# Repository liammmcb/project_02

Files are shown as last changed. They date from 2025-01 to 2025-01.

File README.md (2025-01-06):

# Replica Lightsaber PCB

This repository contains all needed files to create a PCB for the lightsaber as outlined in the lightsaber directory. The purpose of the PCB is to recreate all hardware connectivity currently being used by the PocketBeagle.

The EAGLE folder contains all files related to the EAGLE app, a PCB designer. It contains the library file (.lbr), the schematic file (.sch) and the board layout file (.brd) for the lightsaber PCB. The MFG-folder contains all files for PCB manufacturing, including assembly files, drill files, and gerber files.

The docs folder contains a PowerPoint outlining the background of the project, along with various block diagrams. Additionally, the top and bottom layers of the PCB, along with the schematic are included in this folder.

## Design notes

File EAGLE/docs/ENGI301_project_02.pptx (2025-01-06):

## EDES 301 PCB Project

Liam McConnico-Blanchet
Due 12/17/2024 @ 11:59pm

## Background Information

- I’ve wanted to have my own replica lightsaber for a long time, but they’re too expensive
  - Being able to make our own lightsaber means it will be both cheaper and more personal
  - Since I don’t want an exact lightsaber replica, I will be able to add a lot more features than a regular replica lightsaber.
  - Similar projects
    - NeoPixel Lightsaber: https://www.hackster.io/Modustrial_Maker/neopixel-lightsabers-w-party-modes-arduino-controlled-3e5a0d
    - ENGI 301 Elemental Cosplay Sword: https://www.hackster.io/Eunice011/elemental-cosplay-sword-1821f4
    - Wizard’s Walking Staff: https://www.hackster.io/Lucas_Ainsworth/wizard-s-walking-staff-ed7e08
- Incorporate aspects of different designs (movement of the wizard staff, lightsaber-ness of the NeoPixel Lightsaber, light ups of ENGI 301 cosplay sword) to get a fuller lightsaber experience.

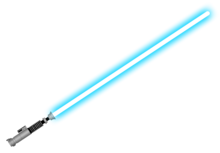
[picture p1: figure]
Lightsaber - Wikipedia

X =

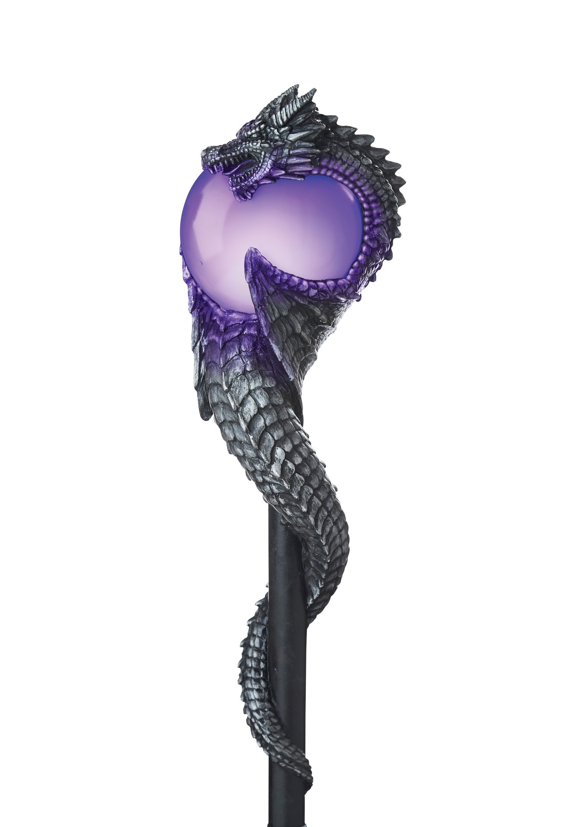
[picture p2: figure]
Amazon.com: California Costumes Wizard Staff : Clothing, Shoes & Jewelry

ENGI 301
Lightsaber
Staff

## System Block Diagram

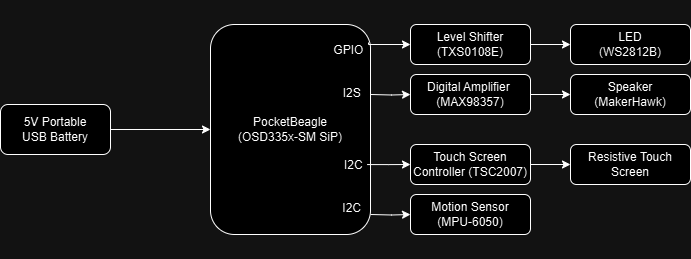
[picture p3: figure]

## Software Block Diagram

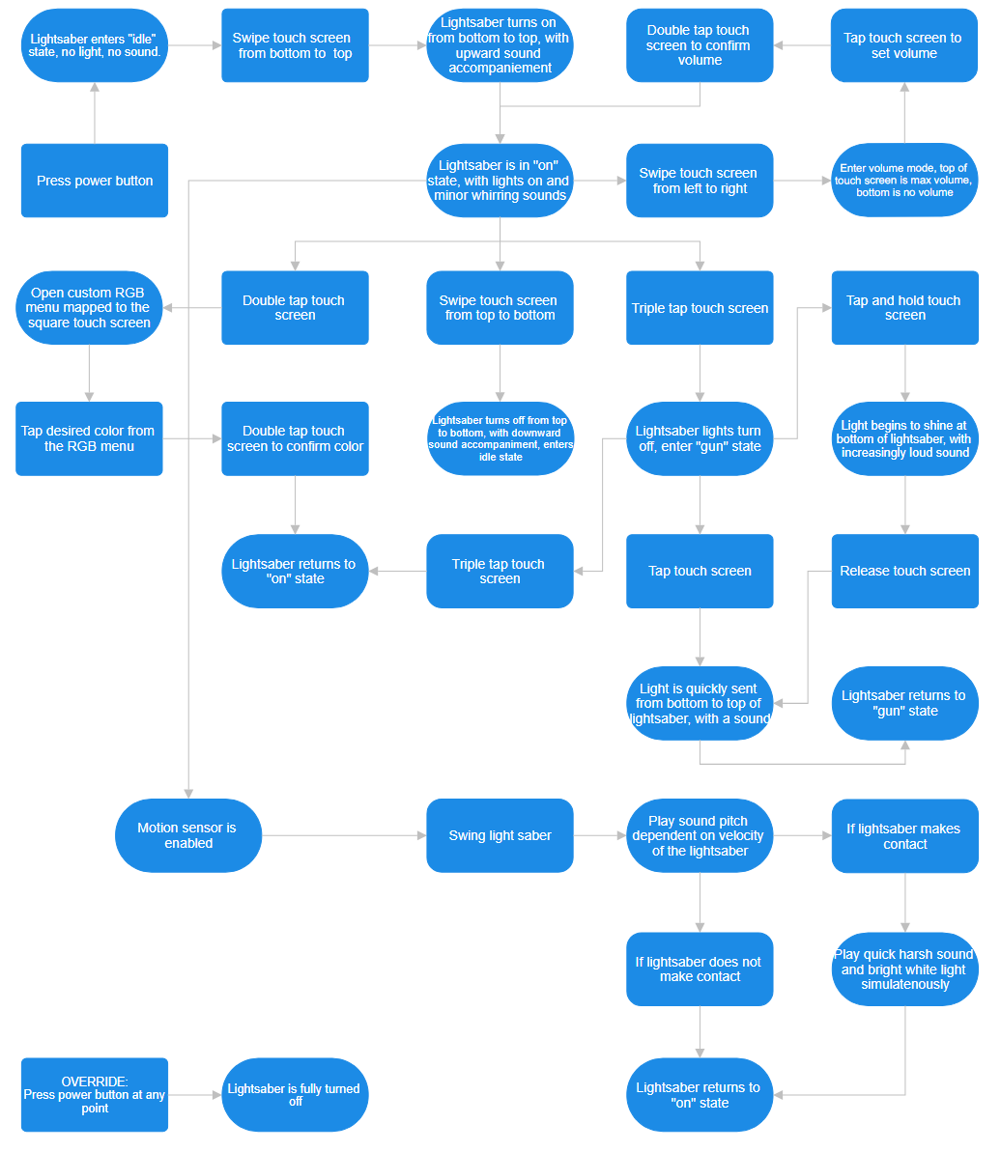
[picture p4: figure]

## Mechanical Block Diagram

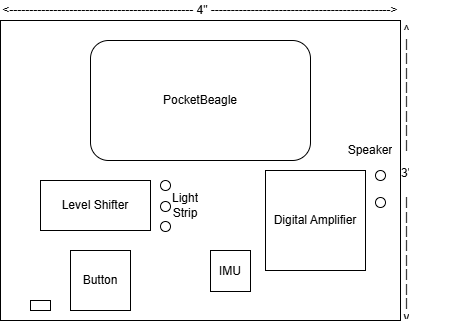
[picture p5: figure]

Complete For Project 2
See next slide for an example

FRONT

BACK

FRONT

## Bill of Materials

Component | Cost
LED Reel (16.4ft) (https://www.amazon.com/BTF-LIGHTING-Flexible-Individually-Addressable-Non-waterproof/dp/B01CDTEJBG) | $27.99
IMU 5pc (https://www.amazon.com/MPU-6050-MPU6050-Accelerometer-Gyroscope-Converter/dp/B07RXQGGJX?th=1) | $12.99
Speakers 2pc (https://www.amazon.com/MakerHawk-Full-Range-Advertising-Connector-Separating/dp/B07GJ4GH67) | $11.99
Digital Amplifier (https://www.adafruit.com/product/3006?gad_source=1) | $5.95
5V Portable USB Battery 2pc (https://www.amazon.com/SIXTHGU-Portable-Charger-Charging-Flashlight/dp/B0C7PHKKNK) | $17.99
Resistive Touch Screen (https://www.adafruit.com/product/333) | $5.95
Resistive Touch Screen Controller (https://www.adafruit.com/product/5423) | $4.95
Total | $87.81

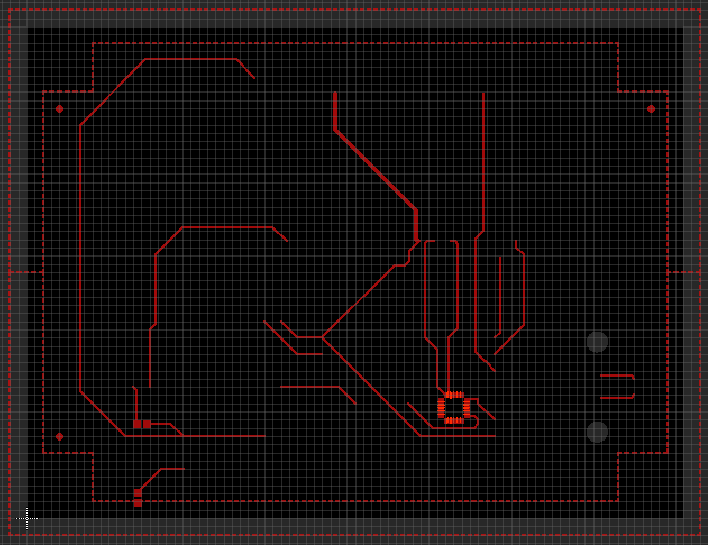
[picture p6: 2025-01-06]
EAGLE/docs/top_layer.png

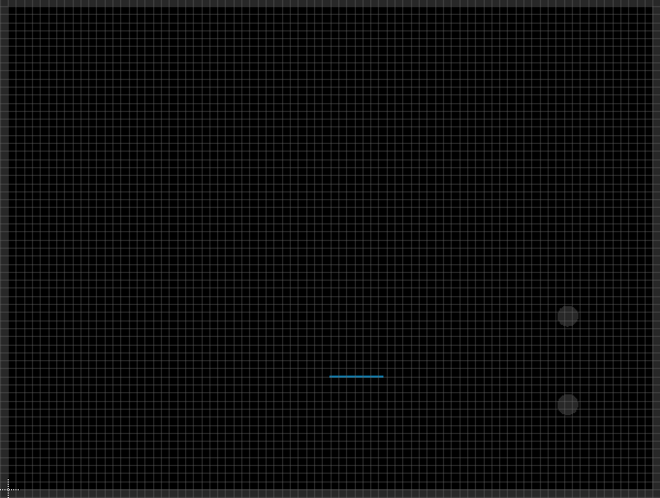
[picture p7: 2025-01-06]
EAGLE/docs/bot_layer.png

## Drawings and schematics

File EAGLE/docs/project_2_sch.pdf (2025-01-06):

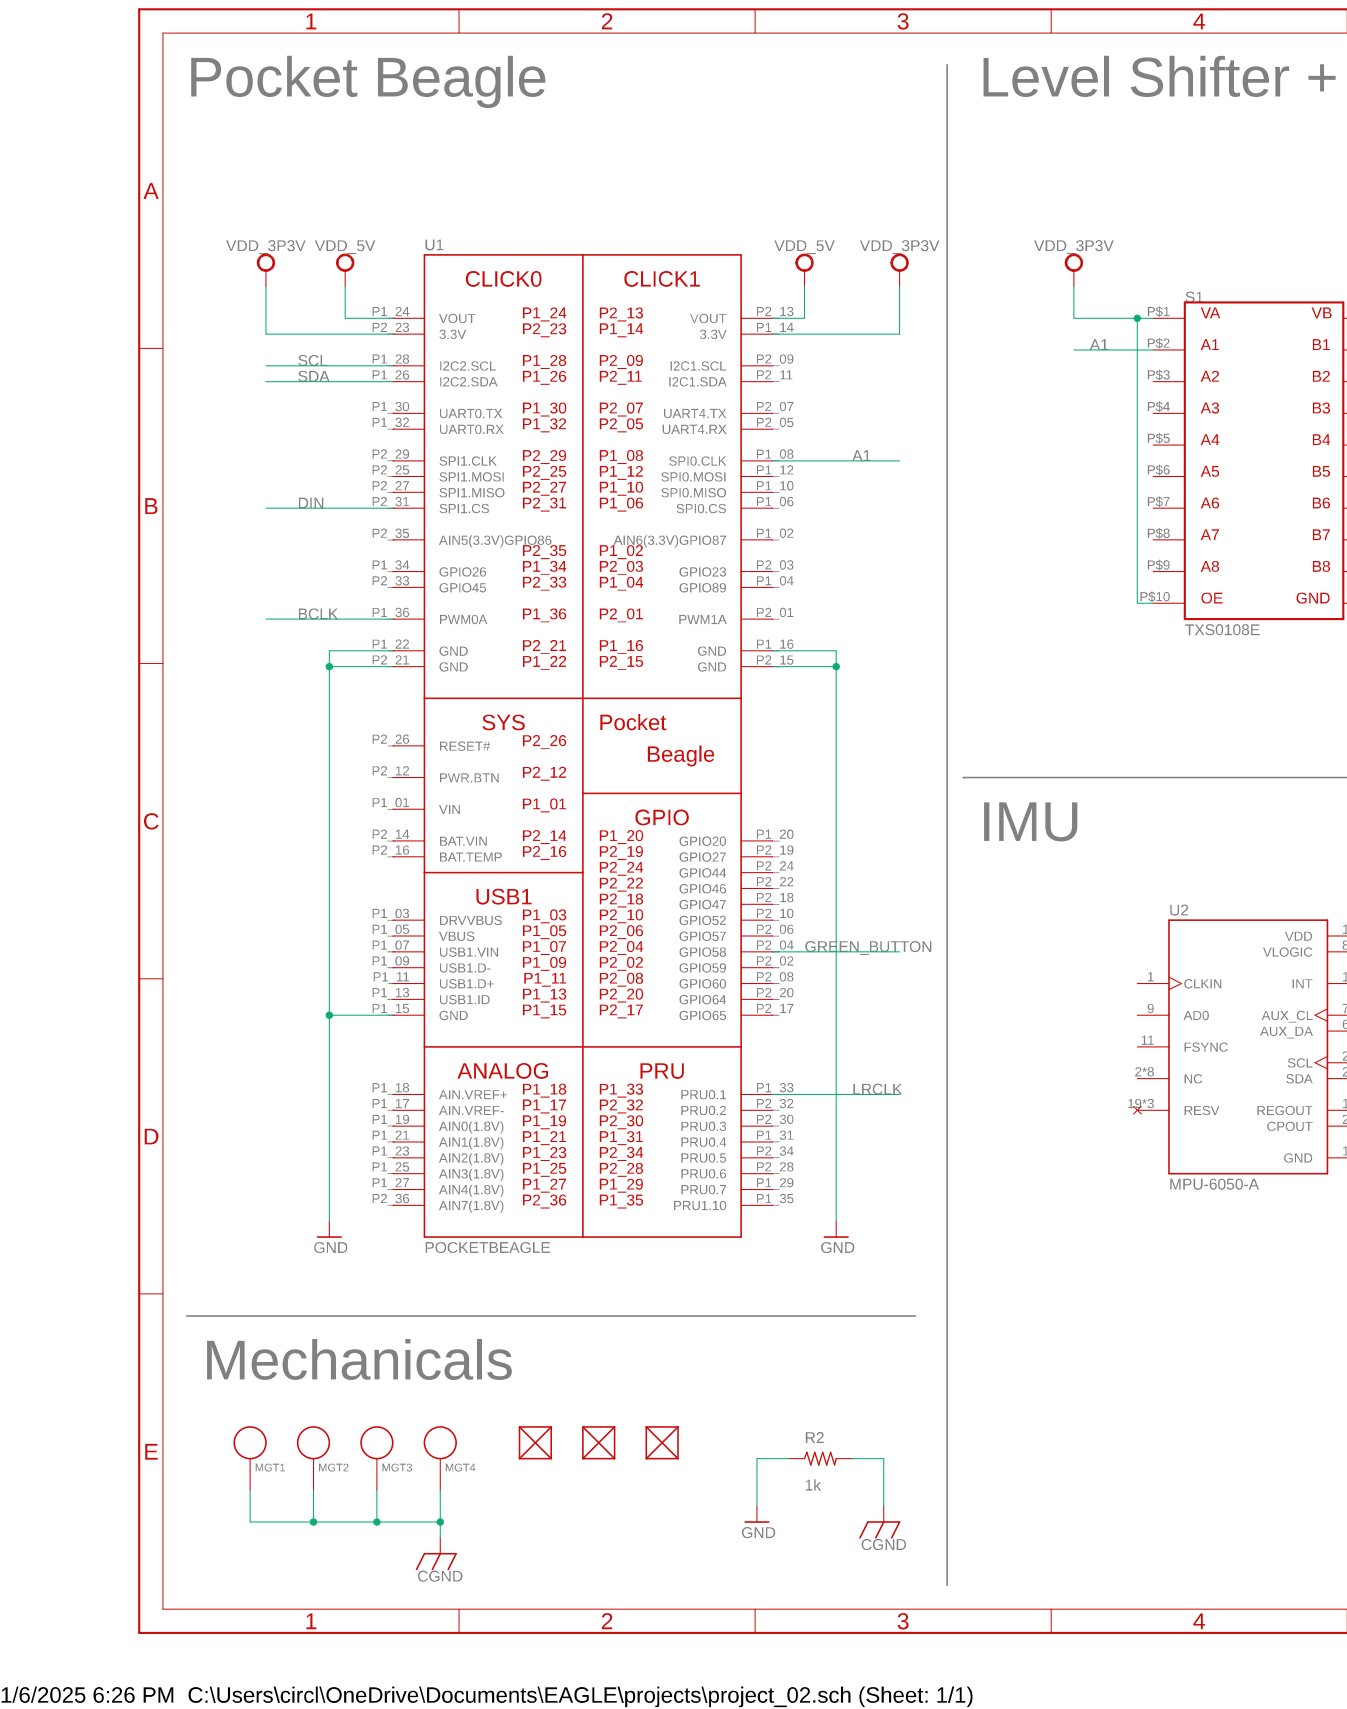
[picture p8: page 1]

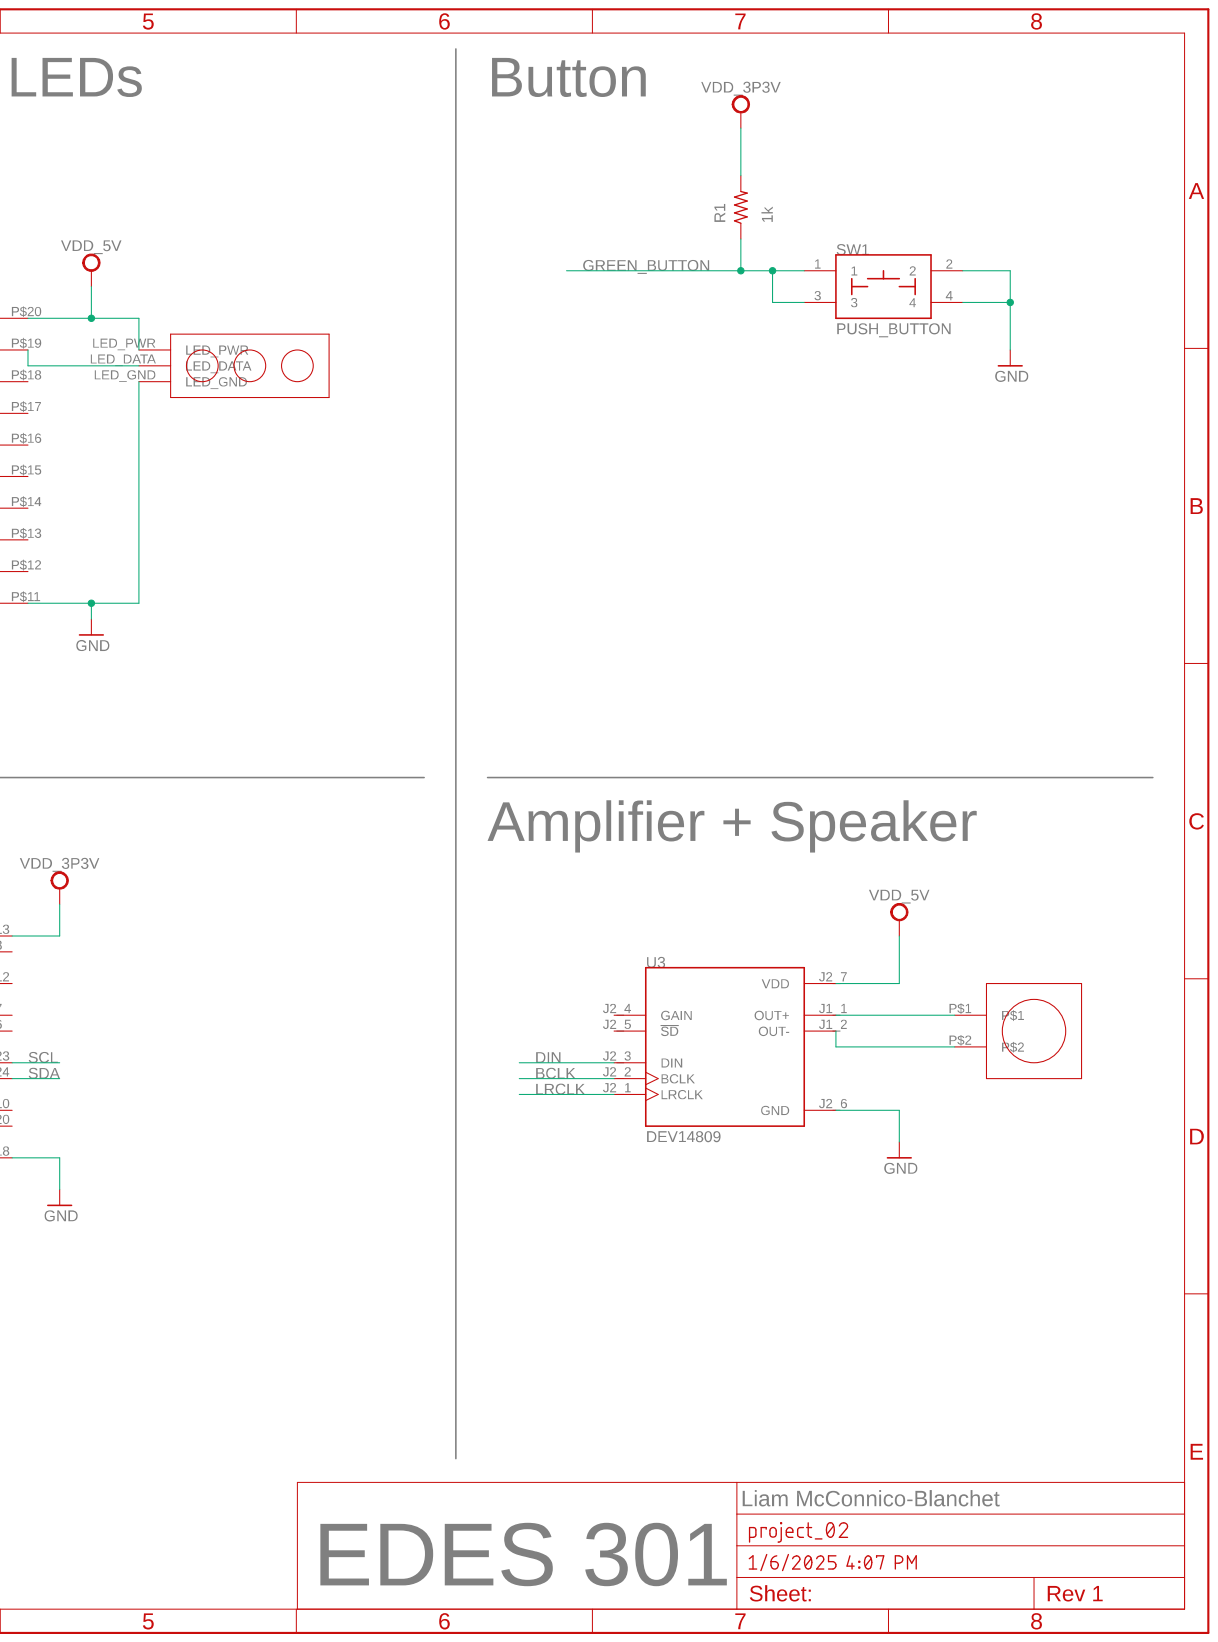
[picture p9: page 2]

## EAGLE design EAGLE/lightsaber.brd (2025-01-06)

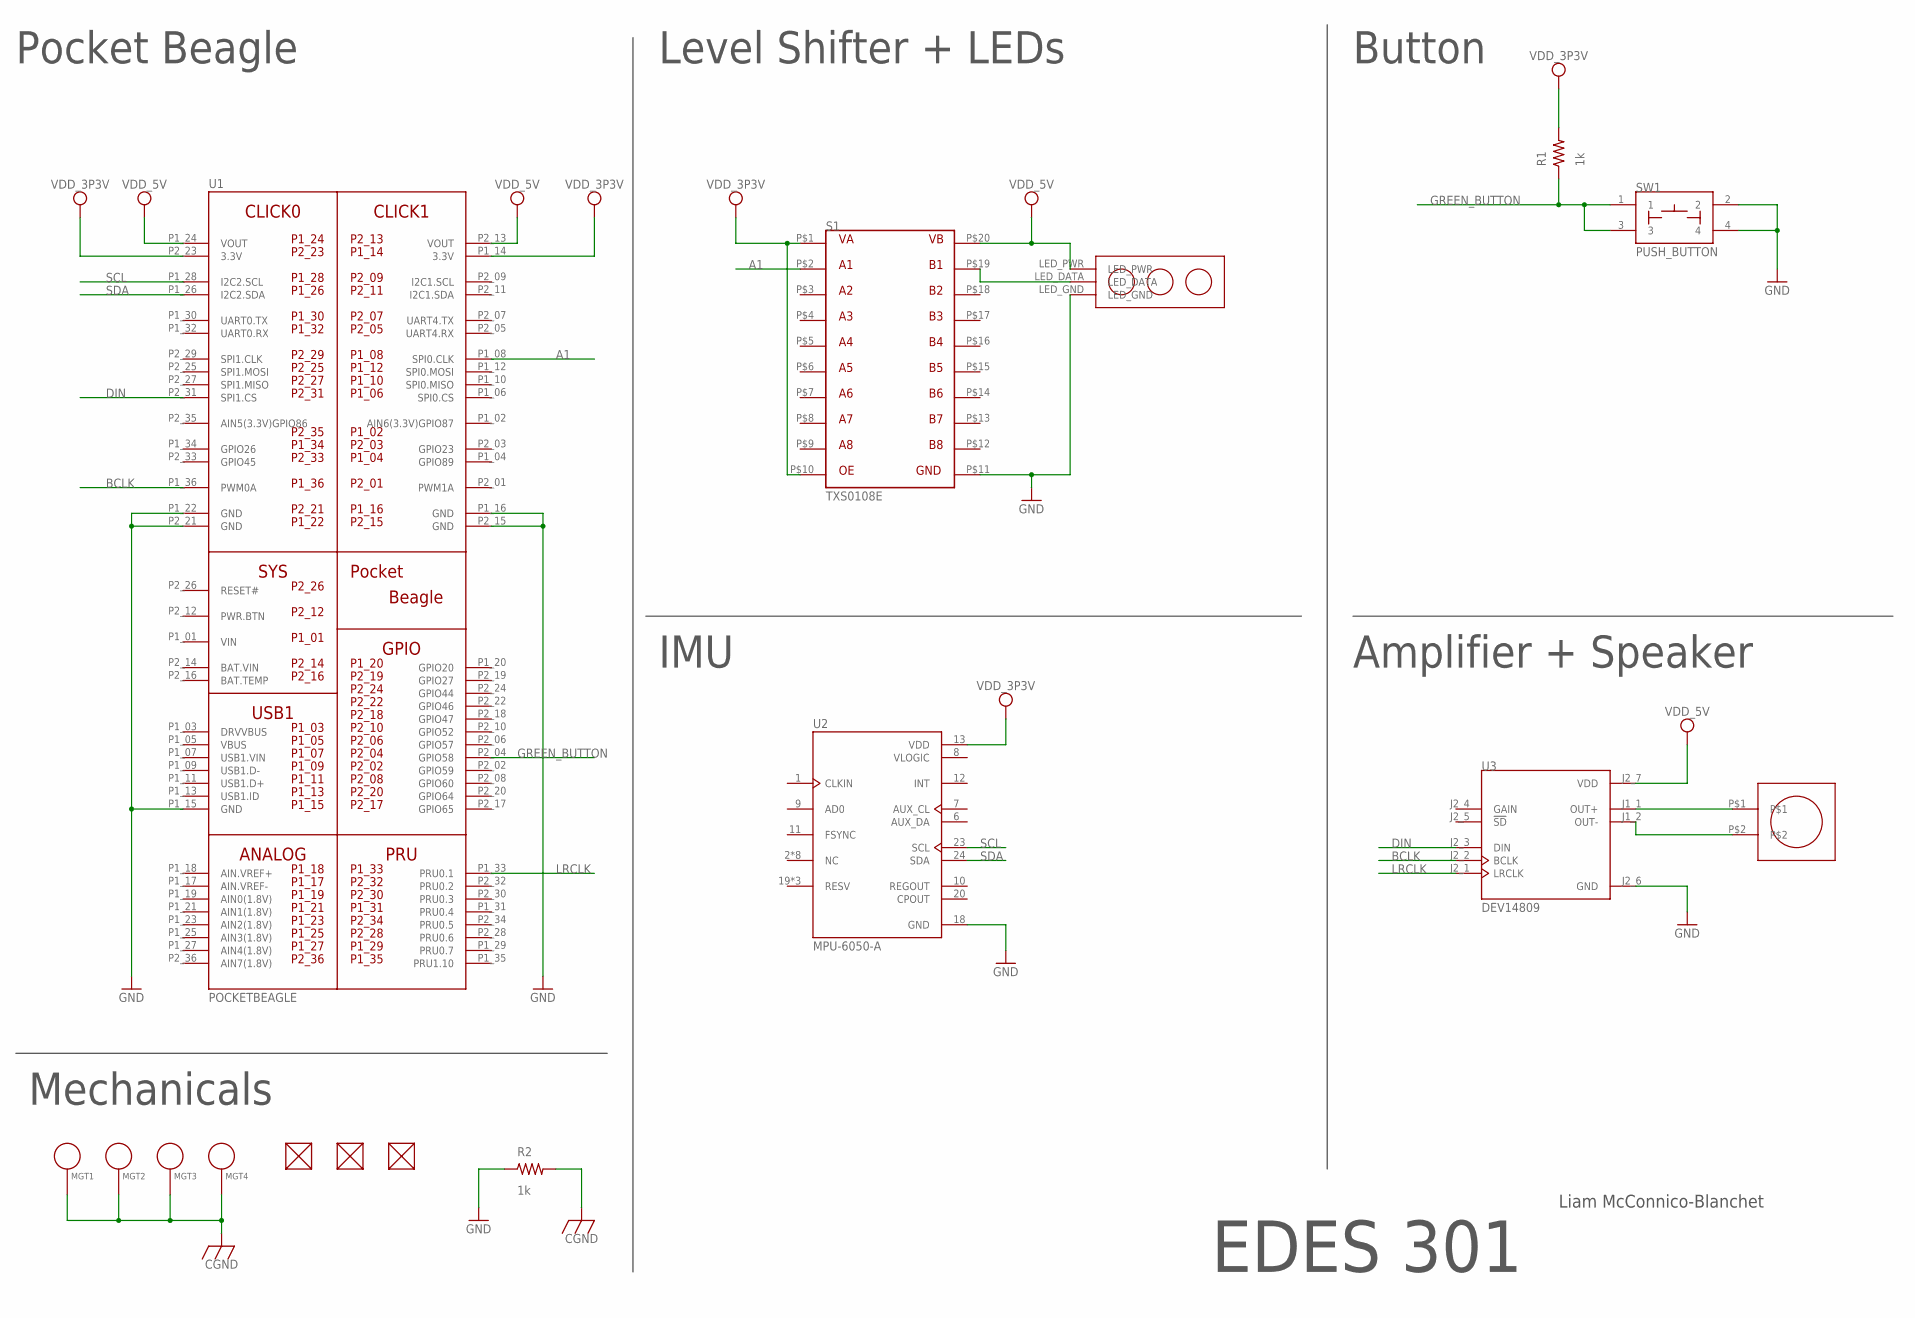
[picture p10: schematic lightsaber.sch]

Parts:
FUD1, FUD2, FUD3: FIDUCIAL; FIDUCIAL_40MIL
MGT1, MGT2, MGT3, MGT4: MOUNTING_HOLE
R1, R2: 1k; R0603
S1: TXS0108E
SW1: PUSH_BUTTON; BUTTON_12.5MM
U1: POCKETBEAGLE
U2: MPU-6050-A; QFN50P400X400X95-24N
U3: DEV14809; MODULE_DEV14809
U$1: LED_STRIP
U$2: SPEAKER

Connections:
A1: S1.P$2, U1.P1_08 (SPI0.CLK)
BAT.VIN: U1.P2_14 (BAT.VIN)
BCLK: U1.P1_36 (PWM0A), U3.J2_2 (BCLK)
CGND: MGT1.P$1, MGT2.P$1, MGT3.P$1, MGT4.P$1, R2.2
DIN: U1.P2_31 (SPI1.CS), U3.J2_3 (DIN)
GND: R2.1, S1.P$11, SW1.2, SW1.4, U1.P1_15 (GND), U1.P1_16 (GND), U1.P1_22 (GND), U1.P2_15 (GND), U1.P2_21 (GND), U2.18 (GND), U3.J2_6 (GND), U$1.LED_GND
GREEN_BUTTON: R1.1, SW1.1, SW1.3, U1.P2_04 (GPIO58)
LRCLK: U1.P1_33 (PRU0.1), U3.J2_1 (LRCLK)
unnamed: U3.J1_1 (OUT+), U$2.P$1
unnamed: U3.J1_2 (OUT-), U$2.P$2
unnamed: S1.P$19, U$1.LED_DATA
SCL: U1.P1_28 (I2C2.SCL), U2.23 (SCL)
SDA: U1.P1_26 (I2C2.SDA), U2.24 (SDA)
VDD_3P3V: R1.2, S1.P$1, S1.P$10, U1.P1_14 (3.3V), U1.P2_23 (3.3V), U2.13 (VDD)
VDD_5V: S1.P$20, U1.P1_24 (VOUT), U1.P2_13 (VOUT), U3.J2_7 (VDD), U$1.LED_PWR
VIN: U1.P1_01 (VIN)
VLOGIC: U2.8 (VLOGIC)

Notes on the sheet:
Pocket Beagle
Level Shifter + LEDs
Button
IMU
Amplifier + Speaker
Mechanicals
EDES 301
Liam McConnico-Blanchet

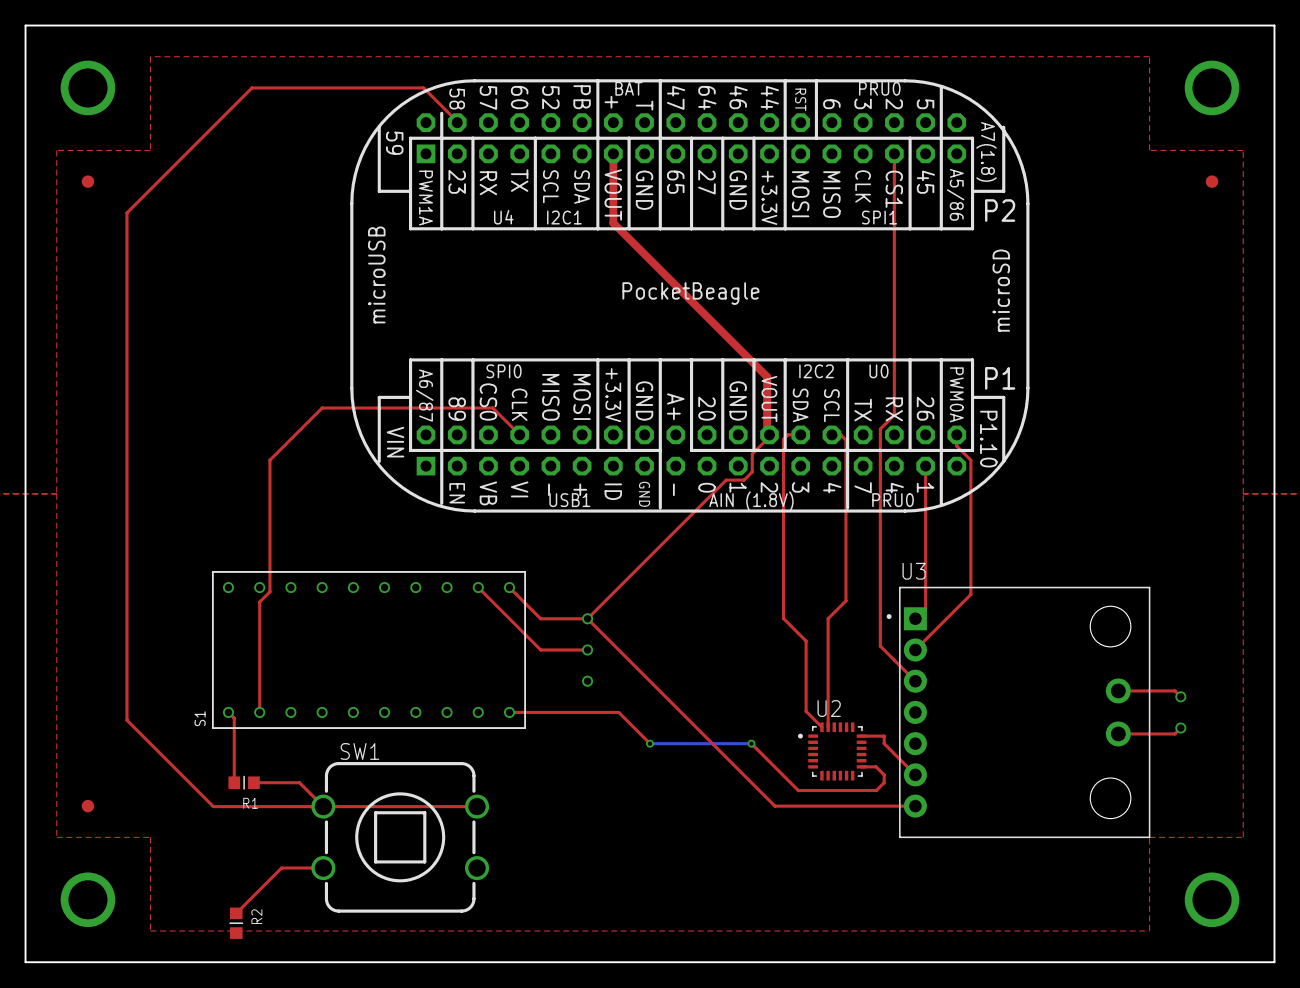
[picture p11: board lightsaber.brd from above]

Board: 4 copper layers, 101.6 x 76.2 mm, 16 parts (0 on the bottom side), 14 nets.

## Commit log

2025-01-07 Create temp.txt
    Create DrillFiles folder
2025-01-07 Create temp.txt
    Create GerberFiles folder
